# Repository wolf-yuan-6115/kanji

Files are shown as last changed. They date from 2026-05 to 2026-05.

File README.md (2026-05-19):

# Kanji

Kanji is an ESP32 based Wi-Fi smart clock. Featuring E-ink display, it can pull weather data, calendar and display realtime clock. It is designed to be a simple and elegant clock that can be placed on a desk. There's also a SHT40 temperature and humidity sensor to provide more information.

Case was not designed and it's intended to just directly use screw as stand.

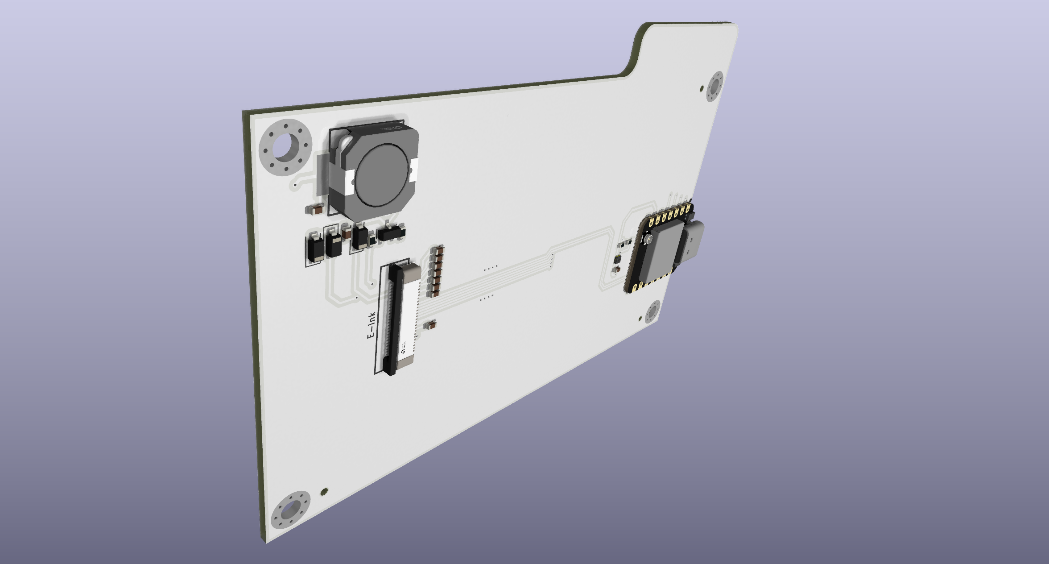
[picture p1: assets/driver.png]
Driver


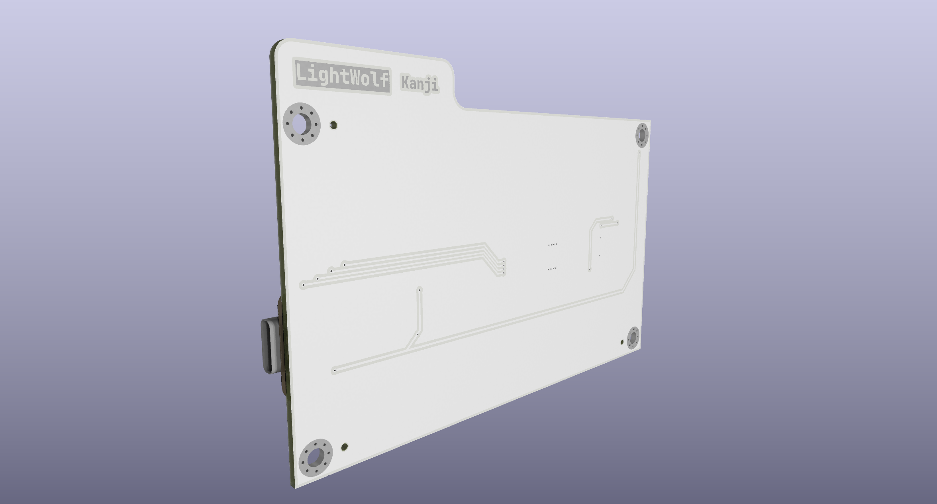
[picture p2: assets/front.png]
front


> Note that display is not here yet because it's going to order seperately.

## Schematic

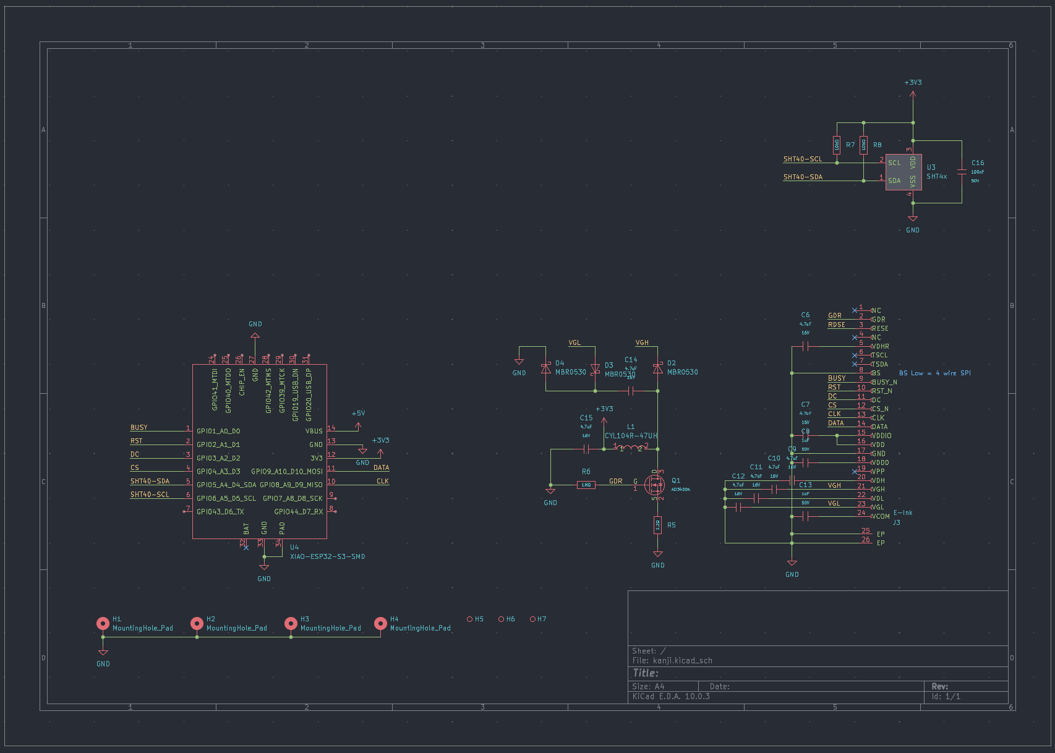
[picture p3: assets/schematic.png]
schematic


## Routing

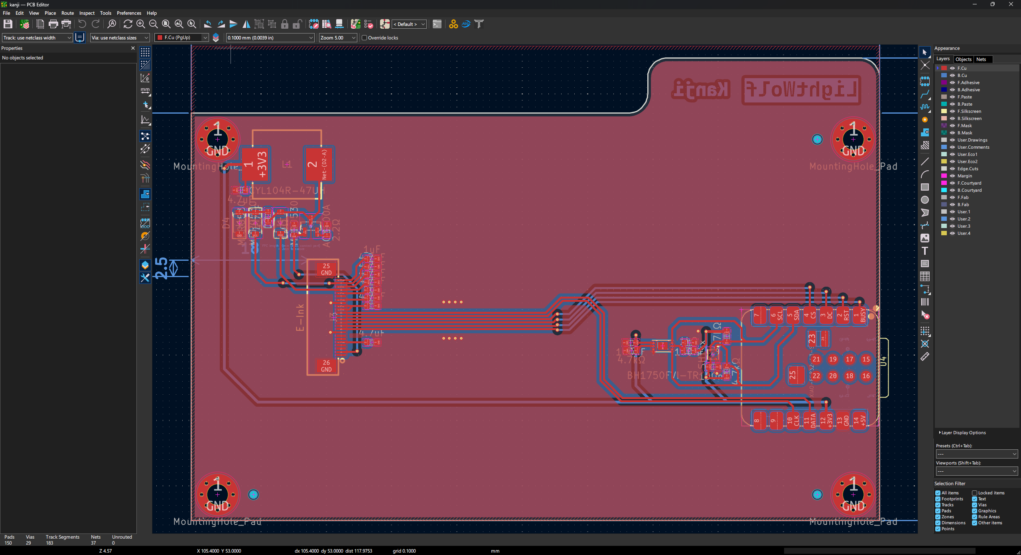
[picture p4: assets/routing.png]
routing


## BOM

| Name | Qty | Total (USD) | Distributor |
| --- | --- | --- | --- |
| WaveShare E-Ink display & Seeed Xiao ESP32-S3 | 1 | $35.00 | Taobao (Like Aliexpress but China version) |
| PCB Assambly | 1 | $44.84 | JLCPCB |
| PCB | 1 | $10.56 | JLCPCB |
| Shipping | 1 | $6.12 | JLCPCB |
| Total | 1 | $96.52 | - |

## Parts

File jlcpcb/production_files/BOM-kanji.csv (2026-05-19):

Comment | Designator | Footprint | LCSC | Quantity
100nF | C1,C16,C17 | C_0603 | C14663 | 3
1MΩ | R6 | R_0603 | C22935 | 1
1kΩ | R2 | R_0603 | C21190 | 1
1uF | C13,C8 | C_0603 | C15849 | 2
2.2Ω | R5 | R_0603 | C22939 | 1
4.7kΩ | R1,R10,R9 | R_0603 | C23162 | 3
4.7uF | C10,C11,C12,C14,C15,C6,C7,C9 | C_0603 | C19666 | 8
AO3400A | Q1 | Q_SOT-23 | C20917 | 1
BH1750FVI-TR | U1 | WSOF-6_L2.6-W1.6-P0.50-TL-EP | C78960 | 1
CYL104R-47UH | L1 | IND-SMD_L10.5-W10.5 | C7431100 | 1
E-Ink | J3 | FPC-SMD_AFC07-S24FCC-00 | C11057 | 1
MBR0530 | D2,D3,D4 | D_SOD-123 | C77336 | 3
SHT4x | U3 | Sensirion_DFN-4_1.5x1.5mm_P0.8mm_SHT4x_NoCentralPad | C2909890 | 1

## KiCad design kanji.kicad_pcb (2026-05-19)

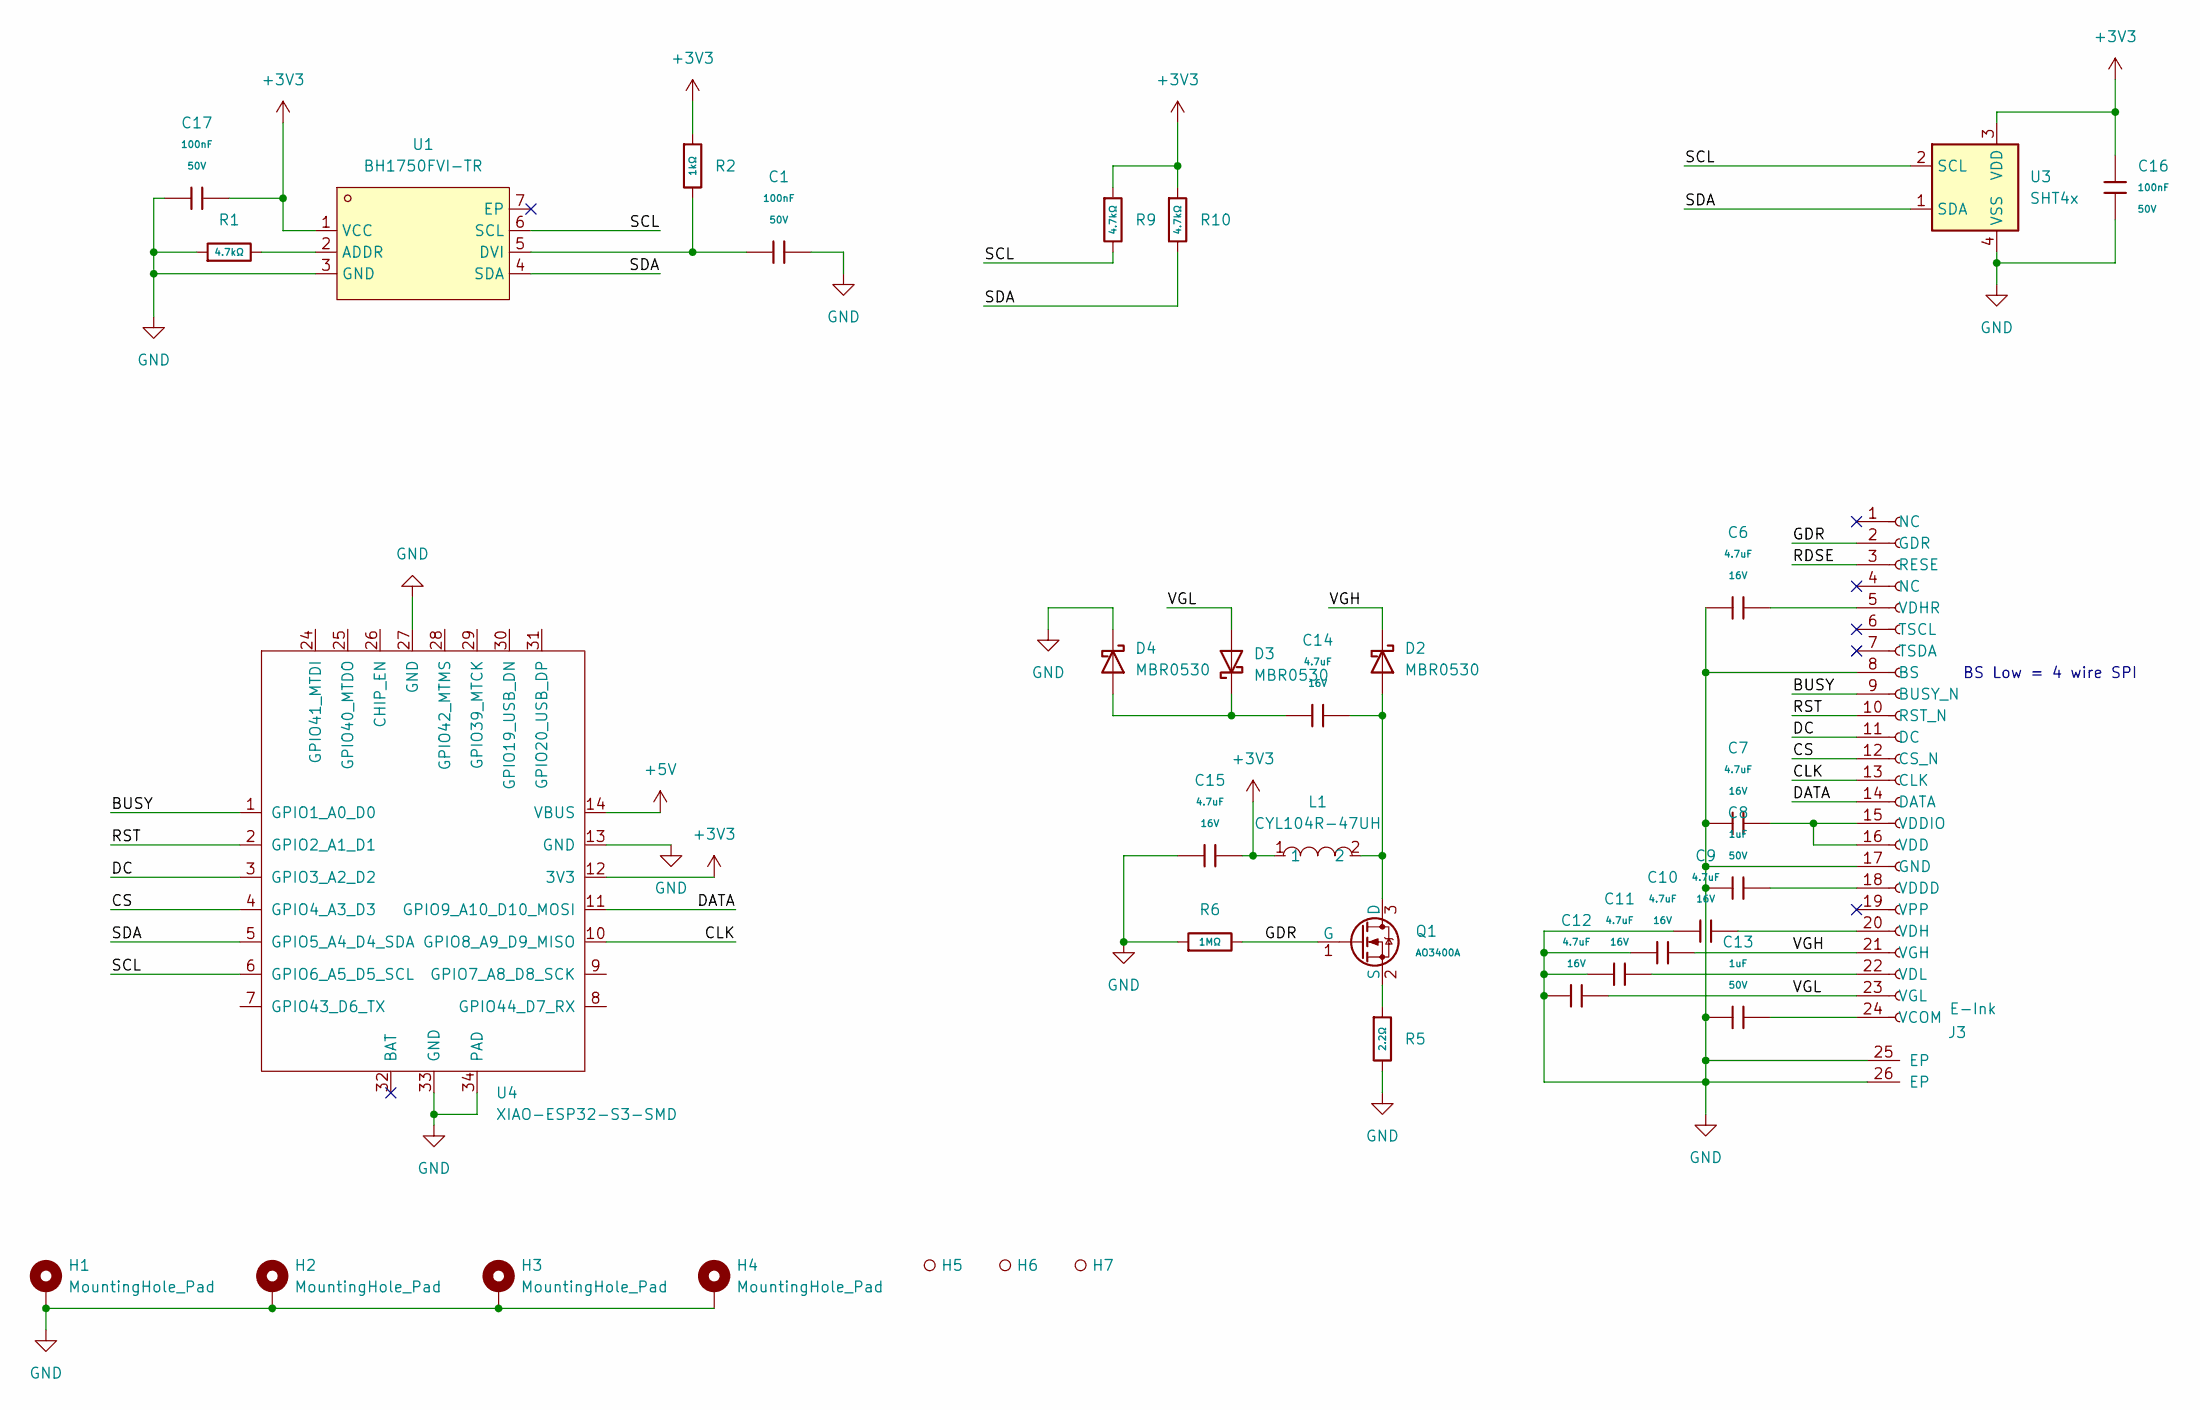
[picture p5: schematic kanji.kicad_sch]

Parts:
C1, C16, C17: 100nF; C_0603; Voltage Rated 50V; Tolerance ±10%; Part CC0603KRX7R9BB104; LCSC C14663
C6, C7, C9, C10, C11, C12, C14, C15: 4.7uF; C_0603; Voltage Rated 16V; Tolerance ±10%; Part CL10A475KO8NNNC; LCSC C19666
C8, C13: 1uF; C_0603; Voltage Rated 50V; Tolerance ±10%; Part CL10A105KB8NNNC; LCSC C15849
D2, D3, D4: MBR0530; D_SOD-123
H1, H2, H3, H4: MountingHole_Pad; MountingHole_3.2mm_M3_Pad_Via
H5, H6, H7: Hole_Tooling_JLCPCB
J3: E-Ink; FPC-SMD_AFC07-S24FCC-00
L1: CYL104R-47UH; IND-SMD_L10.5-W10.5; MPN CYL104R-47UH; LCSC Part C7431100
Q1: AO3400A; Q_SOT-23; Part AO3400A; LCSC C20917
R1, R9, R10: 4.7kΩ; R_0603; Overload Voltage (Max) 75V; Tolerance ±1%; Part 0603WAF4701T5E; LCSC C23162
R2: 1kΩ; R_0603; Overload Voltage (Max) 75V; Tolerance ±1%; Part 0603WAF1001T5E; LCSC C21190
R5: 2.2Ω; R_0603; Overload Voltage (Max) 75V; Tolerance ±1%; Part 0603WAF220KT5E; LCSC C22939
R6: 1MΩ; R_0603; Overload Voltage (Max) 75V; Tolerance ±1%; Part 0603WAF1004T5E; LCSC C22935
U1: BH1750FVI-TR; WSOF-6_L2.6-W1.6-P0.50-TL-EP; MPN BH1750FVI-TR; LCSC Part C78960
U3: SHT4x; Sensirion_DFN-4_1.5x1.5mm_P0.8mm_SHT4x_NoCentralPad; LCSC C2909890
U4: XIAO-ESP32-S3-SMD

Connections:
+3V3: C15.2, C16.1, C17.2, L1.1, R2.1, R9.1, R10.1, U1.1 (VCC), U3.3 (VDD), U4.12 (3V3)
+5V: U4.14 (VBUS)
/BUSY: J3.9 (BUSY_N), U4.1 (GPIO1_A0_D0)
/CLK: J3.13 (CLK), U4.10 (GPIO8_A9_D9_MISO)
/CS: J3.12 (CS_N), U4.4 (GPIO4_A3_D3)
/DATA: J3.14 (DATA), U4.11 (GPIO9_A10_D10_MOSI)
/DC: J3.11 (DC), U4.3 (GPIO3_A2_D2)
/GDR: J3.2 (GDR), Q1.1 (G), R6.2
/RDSE: J3.3 (RESE)
/RST: J3.10 (RST_N), U4.2 (GPIO2_A1_D1)
/SCL: R9.2, U1.6 (SCL), U3.2 (SCL), U4.6 (GPIO6_A5_D5_SCL)
/SDA: R10.2, U1.4 (SDA), U3.1 (SDA), U4.5 (GPIO5_A4_D4_SDA)
/VGH: C10.2, D2.1 (K), J3.21 (VGH)
/VGL: C12.2, D3.2 (A), J3.23 (VGL)
GND: C1.2, C6.1, C7.1, C8.1, C9.1, C10.1, C11.1, C12.1, C13.1, C15.1, C16.2, C17.1, D4.1 (K), H1.1 (1_1), H2.1 (1_1), H3.1 (1_1), H4.1 (1_1), J3.8 (BS), J3.17 (GND), J3.25 (EP), J3.26 (EP), R1.1, R5.2, R6.1, U1.3 (GND), U3.4 (VSS), U4.13 (GND), U4.27 (GND), U4.33 (GND), U4.34 (PAD)
unnamed: C14.2, D2.2 (A), L1.2, Q1.3 (D)
unnamed: C14.1, D3.1 (K), D4.2 (A)
unnamed: C13.2, J3.24 (VCOM)
unnamed: C7.2, J3.15 (VDDIO), J3.16 (VDD)
unnamed: C8.2, J3.18 (VDDD)
unnamed: C9.2, J3.20 (VDH)
unnamed: C6.2, J3.5 (VDHR)
unnamed: C11.2, J3.22 (VDL)
unnamed: Q1.2 (S), R5.1
unnamed: R1.2, U1.2 (ADDR)
unnamed: C1.1, R2.2, U1.5 (DVI)

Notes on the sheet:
BS Low = 4 wire SPI

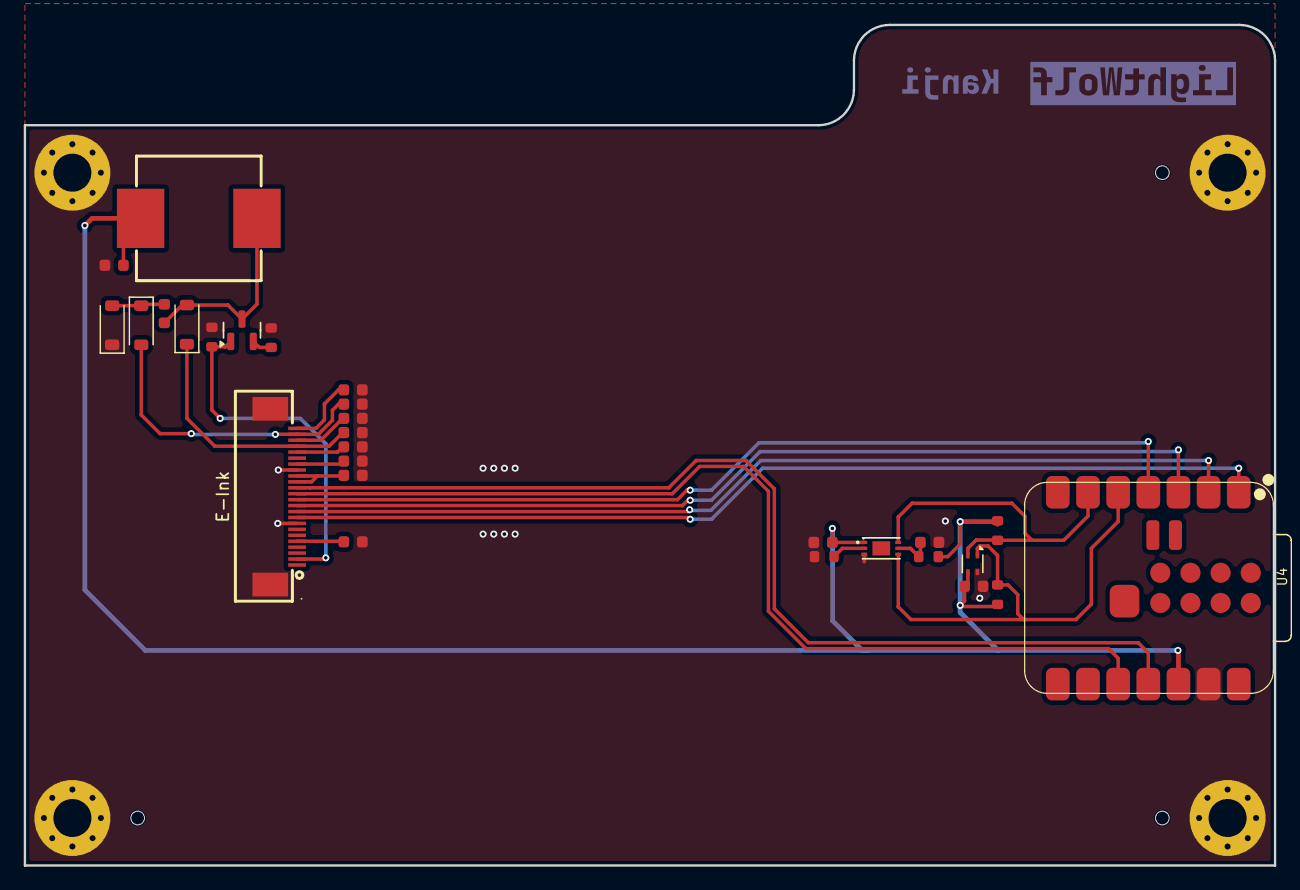
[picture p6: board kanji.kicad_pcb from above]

Board: 2 copper layers, 105.3 x 70.8 mm, 35 parts (0 on the bottom side), 24 nets.

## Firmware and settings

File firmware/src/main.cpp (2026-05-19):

#include <Arduino.h>
#include <WiFi.h>
#include <WiFiClientSecure.h>
#include <HTTPClient.h>
#include <ArduinoJson.h>
#include <time.h>
#include <Wire.h>
#include <Adafruit_SHT4x.h>
#include <esp_heap_caps.h>

#include "app_config.h"
#include "vendor/waveshare_4in26g/EPD_4in26g.h"
#include "vendor/waveshare_4in26g/GUI_Paint.h"
#include "vendor/waveshare_4in26g/fonts.h"

namespace {

constexpr int I2C_SDA_PIN = 5;
constexpr int I2C_SCL_PIN = 6;
constexpr uint32_t I2C_FREQ = 100000;
constexpr uint8_t BH1750_ADDR = 0x23;
constexpr uint32_t LIGHT_UPDATE_MS = 1000UL;
constexpr float LIGHT_PRESENT_LUX = 10.0f;
constexpr float LIGHT_ABSENT_LUX = 5.0f;
constexpr uint32_t CLOCK_REFRESH_SECONDS = 5UL * 60UL;

constexpr uint16_t DISPLAY_WIDTH = EPD_4IN26G_WIDTH;
constexpr uint16_t DISPLAY_HEIGHT = EPD_4IN26G_HEIGHT;
constexpr uint16_t LEFT_PANE_WIDTH = (DISPLAY_WIDTH * 2) / 3;
constexpr uint16_t RIGHT_PANE_X = LEFT_PANE_WIDTH;
constexpr uint16_t RIGHT_PANE_WIDTH = DISPLAY_WIDTH - LEFT_PANE_WIDTH;
constexpr uint16_t RIGHT_BOTTOM_ZONE_HEIGHT = 120;
constexpr uint16_t RIGHT_BOTTOM_Y = DISPLAY_HEIGHT - RIGHT_BOTTOM_ZONE_HEIGHT;
constexpr uint32_t SENSOR_UPDATE_MS = 5UL * 60UL * 1000UL;
constexpr uint32_t WEATHER_UPDATE_MS = 60UL * 60UL * 1000UL;
constexpr uint32_t NTP_RESYNC_MS = 24UL * 60UL * 60UL * 1000UL;

struct WeatherData {
  bool valid = false;
  int temp_c = 0;
  int humidity = 0;
  int weather_code = 0;
  int wind_kmph = 0;
  char description[40] = "--";
};

struct SensorData {
  bool valid = false;
  float temp_c = 0.0f;
  float humidity = 0.0f;
};

UBYTE* g_framebuffer = nullptr;
UDOUBLE g_framebuffer_size = 0;
bool g_using_psram = false;

Adafruit_SHT4x g_sht4;
bool g_sensor_ok = false;
WeatherData g_weather;
SensorData g_sensor;
bool g_light_sensor_ok = false;
bool g_light_present = true;
bool g_light_state_known = false;
bool g_light_present_trigger = false;
float g_light_lux = 0.0f;

uint32_t g_last_light_update = 0;
uint32_t g_last_sensor_update = 0;
uint32_t g_last_weather_update = 0;
uint32_t g_last_ntp_sync = 0;
time_t g_next_clock_refresh = 0;
bool g_pending_render = false;

tm g_timeinfo = {};
bool g_time_ok = false;

time_t nextFiveMinuteBoundary(time_t epoch) {
  return ((epoch / static_cast<time_t>(CLOCK_REFRESH_SECONDS)) + 1) * static_cast<time_t>(CLOCK_REFRESH_SECONDS);
}

void scheduleNextClockRefresh() {
  const time_t now_epoch = time(nullptr);
  if (now_epoch > 0) {
    g_next_clock_refresh = nextFiveMinuteBoundary(now_epoch);
  }
}

void advanceNextClockRefresh(time_t now_epoch) {
  if (g_next_clock_refresh == 0) {
    return;
  }

  while (g_next_clock_refresh <= now_epoch) {
    g_next_clock_refresh += static_cast<time_t>(CLOCK_REFRESH_SECONDS);
  }
}

bool bh1750WriteCommand(uint8_t command) {
  Wire.beginTransmission(BH1750_ADDR);
  Wire.write(command);
  return Wire.endTransmission() == 0;
}

bool initLightSensor() {
  g_last_light_update = millis();

  Wire.beginTransmission(BH1750_ADDR);
  if (Wire.endTransmission() != 0) {
    g_light_sensor_ok = false;
    return false;
  }

  if (!bh1750WriteCommand(0x01)) {
    g_light_sensor_ok = false;
    return false;
  }

  delay(5);

  if (!bh1750WriteCommand(0x07)) {
    g_light_sensor_ok = false;
    return false;
  }

  delay(5);

  if (!bh1750WriteCommand(0x10)) {
    g_light_sensor_ok = false;
    return false;
  }

  g_light_sensor_ok = true;
  return true;
}

bool readLightSensor(float& lux_out) {
  const uint8_t bytes_read = Wire.requestFrom(BH1750_ADDR, static_cast<uint8_t>(2));
  if (bytes_read != 2) {
    return false;
  }

  const uint16_t raw = (static_cast<uint16_t>(Wire.read()) << 8) | static_cast<uint16_t>(Wire.read());
  lux_out = static_cast<float>(raw) / 1.2f;
  return true;
}

bool pollLightSensor(uint32_t now_ms) {
  if ((now_ms - g_last_light_update) < LIGHT_UPDATE_MS) {
    return false;
  }

  g_last_light_update = now_ms;

  if (!g_light_sensor_ok && !initLightSensor()) {
    g_light_present = true;
    g_light_state_known = false;
    return false;
  }

  float lux = 0.0f;
  if (!readLightSensor(lux)) {
    g_light_sensor_ok = false;
    g_light_present = true;
    g_light_state_known = false;
    return false;
  }

  g_light_lux = lux;
  const bool was_present = g_light_present;

  if (!g_light_state_known) {
    g_light_present = lux >= LIGHT_PRESENT_LUX;
    g_light_state_known = true;
  } else if (lux >= LIGHT_PRESENT_LUX) {
    g_light_present = true;
  } else if (lux <= LIGHT_ABSENT_LUX) {
    g_light_present = false;
  }

  if (!was_present && g_light_present) {
    g_light_present_trigger = true;
    g_pending_render = true;
  }

  return true;
}

void drawWeatherIcon(uint16_t x, uint16_t y, int code) {
  if (code == 113) {
    Paint_DrawCircle(x + 20, y + 20, 12, EPD_4IN26G_YELLOW, DOT_PIXEL_1X1, DRAW_FILL_EMPTY);
    Paint_DrawLine(x + 20, y + 2, x + 20, y + 12, EPD_4IN26G_YELLOW, DOT_PIXEL_1X1, LINE_STYLE_SOLID);
    Paint_DrawLine(x + 20, y + 28, x + 20, y + 38, EPD_4IN26G_YELLOW, DOT_PIXEL_1X1, LINE_STYLE_SOLID);
    Paint_DrawLine(x + 2, y + 20, x + 12, y + 20, EPD_4IN26G_YELLOW, DOT_PIXEL_1X1, LINE_STYLE_SOLID);
    Paint_DrawLine(x + 28, y + 20, x + 38, y + 20, EPD_4IN26G_YELLOW, DOT_PIXEL_1X1, LINE_STYLE_SOLID);
    return;
  }

  if (code >= 176 && code <= 200) {
    Paint_DrawRectangle(x + 6, y + 10, x + 34, y + 26, EPD_4IN26G_BLACK, DOT_PIXEL_1X1, DRAW_FILL_EMPTY);
    Paint_DrawLine(x + 10, y + 28, x + 14, y + 36, EPD_4IN26G_RED, DOT_PIXEL_1X1, LINE_STYLE_SOLID);
    Paint_DrawLine(x + 20, y + 28, x + 24, y + 36, EPD_4IN26G_RED, DOT_PIXEL_1X1, LINE_STYLE_SOLID);
    Paint_DrawLine(x + 30, y + 28, x + 34, y + 36, EPD_4IN26G_RED, DOT_PIXEL_1X1, LINE_STYLE_SOLID);
    return;
  }

  if ((code >= 80 && code <= 99) || code == 263 || code == 266) {
    Paint_DrawRectangle(x + 6, y + 10, x + 34, y + 26, EPD_4IN26G_BLACK, DOT_PIXEL_1X1, DRAW_FILL_EMPTY);
    Paint_DrawLine(x + 10, y + 28, x + 10, y + 36, EPD_4IN26G_BLACK, DOT_PIXEL_1X1, LINE_STYLE_SOLID);
    Paint_DrawLine(x + 20, y + 28, x + 20, y + 36, EPD_4IN26G_BLACK, DOT_PIXEL_1X1, LINE_STYLE_SOLID);
    Paint_DrawLine(x + 30, y + 28, x + 30, y + 36, EPD_4IN26G_BLACK, DOT_PIXEL_1X1, LINE_STYLE_SOLID);
    return;
  }

  if (code == 116 || code == 119 || code == 122) {
    Paint_DrawRectangle(x + 6, y + 12, x + 34, y + 30, EPD_4IN26G_BLACK, DOT_PIXEL_1X1, DRAW_FILL_EMPTY);
    Paint_DrawCircle(x + 14, y + 12, 6, EPD_4IN26G_BLACK, DOT_PIXEL_1X1, DRAW_FILL_EMPTY);
    Paint_DrawCircle(x + 24, y + 10, 7, EPD_4IN26G_BLACK, DOT_PIXEL_1X1, DRAW_FILL_EMPTY);
    return;
  }

  Paint_DrawRectangle(x + 6, y + 10, x + 34, y + 28, EPD_4IN26G_BLACK, DOT_PIXEL_1X1, DRAW_FILL_EMPTY);
  Paint_DrawLine(x + 10, y + 32, x + 30, y + 32, EPD_4IN26G_YELLOW, DOT_PIXEL_1X1, LINE_STYLE_DOTTED);
}

void drawLayoutBorders() {
  Paint_DrawLine(LEFT_PANE_WIDTH, 0, LEFT_PANE_WIDTH, DISPLAY_HEIGHT - 1, EPD_4IN26G_BLACK, DOT_PIXEL_1X1, LINE_STYLE_SOLID);
  Paint_DrawLine(RIGHT_PANE_X, RIGHT_BOTTOM_Y, DISPLAY_WIDTH - 1, RIGHT_BOTTOM_Y, EPD_4IN26G_BLACK, DOT_PIXEL_1X1, LINE_STYLE_SOLID);
}

void drawClockPane() {
  char time_buf[16];
  char date_buf[24];
  if (g_time_ok) {
    strftime(time_buf, sizeof(time_buf), "%H:%M", &g_timeinfo);
    strftime(date_buf, sizeof(date_buf), "%a %Y-%m-%d", &g_timeinfo);
  } else {
    snprintf(time_buf, sizeof(time_buf), "--:--");
    snprintf(date_buf, sizeof(date_buf), "No time sync");
  }

  Paint_DrawString_EN(24, 36, "Clock", &Font20, EPD_4IN26G_BLACK, EPD_4IN26G_WHITE);
  Paint_DrawString_EN(24, 140, time_buf, &Font24, EPD_4IN26G_RED, EPD_4IN26G_WHITE);
  Paint_DrawString_EN(24, 190, date_buf, &Font16, EPD_4IN26G_BLACK, EPD_4IN26G_WHITE);

  if (g_time_ok) {
    char tz_buf[24];
    strftime(tz_buf, sizeof(tz_buf), "%Z", &g_timeinfo);
    Paint_DrawString_EN(24, 222, tz_buf, &Font12, EPD_4IN26G_YELLOW, EPD_4IN26G_WHITE);
  }
}

void drawWeatherPane() {
  Paint_DrawString_EN(RIGHT_PANE_X + 14, 20, "Weather", &Font16, EPD_4IN26G_BLACK, EPD_4IN26G_WHITE);
  drawWeatherIcon(RIGHT_PANE_X + 18, 48, g_weather.weather_code);

  char buf[48];
  if (g_weather.valid) {
    snprintf(buf, sizeof(buf), "%d C", g_weather.temp_c);
    Paint_DrawString_EN(RIGHT_PANE_X + 70, 66, buf, &Font20, EPD_4IN26G_RED, EPD_4IN26G_WHITE);

    snprintf(buf, sizeof(buf), "RH %d%%", g_weather.humidity);
    Paint_DrawString_EN(RIGHT_PANE_X + 14, 110, buf, &Font16, EPD_4IN26G_BLACK, EPD_4IN26G_WHITE);

    snprintf(buf, sizeof(buf), "Wind %dkm", g_weather.wind_kmph);
    Paint_DrawString_EN(RIGHT_PANE_X + 14, 138, buf, &Font12, EPD_4IN26G_YELLOW, EPD_4IN26G_WHITE);

    Paint_DrawString_EN(RIGHT_PANE_X + 14, 162, g_weather.description, &Font12, EPD_4IN26G_BLACK, EPD_4IN26G_WHITE);
  } else {
    Paint_DrawString_EN(RIGHT_PANE_X + 14, 100, "No weather", &Font16, EPD_4IN26G_BLACK, EPD_4IN26G_WHITE);
  }
}

void drawSensorZone() {
  Paint_DrawString_EN(RIGHT_PANE_X + 14, RIGHT_BOTTOM_Y + 12, "Room", &Font16, EPD_4IN26G_BLACK, EPD_4IN26G_WHITE);

  char buf[48];
  if (g_sensor.valid) {
    snprintf(buf, sizeof(buf), "T %.1f C", g_sensor.temp_c);
    Paint_DrawString_EN(RIGHT_PANE_X + 14, RIGHT_BOTTOM_Y + 44, buf, &Font16, EPD_4IN26G_RED, EPD_4IN26G_WHITE);

    snprintf(buf, sizeof(buf), "RH %.1f%%", g_sensor.humidity);
    Paint_DrawString_EN(RIGHT_PANE_X + 14, RIGHT_BOTTOM_Y + 72, buf, &Font16, EPD_4IN26G_BLACK, EPD_4IN26G_WHITE);
  } else {
    Paint_DrawString_EN(RIGHT_PANE_X + 14, RIGHT_BOTTOM_Y + 50, "SHT40 offline", &Font16, EPD_4IN26G_BLACK, EPD_4IN26G_WHITE);
  }
}

void renderAndFlush() {
  Paint_NewImage(g_framebuffer, DISPLAY_WIDTH, DISPLAY_HEIGHT, 0, EPD_4IN26G_WHITE);
  Paint_SetScale(4);
  Paint_SelectImage(g_framebuffer);
  Paint_Clear(EPD_4IN26G_WHITE);

  drawLayoutBorders();
  drawClockPane();
  drawWeatherPane();
  drawSensorZone();

  EPD_4IN26G_Display(g_framebuffer);
}

bool connectWiFi(uint32_t timeout_ms) {
  if (WiFi.status() == WL_CONNECTED) {
    return true;
  }

  WiFi.mode(WIFI_STA);
  WiFi.begin(WIFI_SSID, WIFI_PASSWORD);
  const uint32_t start_ms = millis();
  while (WiFi.status() != WL_CONNECTED && (millis() - start_ms) < timeout_ms) {
    delay(250);
  }
  return WiFi.status() == WL_CONNECTED;
}

bool syncTime() {
  configTzTime(TIMEZONE_TZ, NTP_SERVER_PRIMARY, NTP_SERVER_SECONDARY);
  for (int i = 0; i < 20; ++i) {
    if (getLocalTime(&g_timeinfo, 500)) {
      g_time_ok = true;
      g_last_ntp_sync = millis();
      scheduleNextClockRefresh();
      return true;
    }
    delay(200);
  }
  g_time_ok = false;
  return false;
}

bool refreshLocalTime() {
  g_time_ok = getLocalTime(&g_timeinfo, 100);
  return g_time_ok;
}

bool fetchWeather() {
  if (WiFi.status() != WL_CONNECTED) {
    return false;
  }

  WiFiClientSecure client;
  client.setInsecure();

  HTTPClient http;
  if (!http.begin(client, WEATHER_URL)) {
    return false;
  }

  http.setTimeout(7000);
  const int code = http.GET();
  if (code != HTTP_CODE_OK) {
    http.end();
    return false;
  }

  JsonDocument doc;
  DeserializationError err = deserializeJson(doc, http.getStream());
  http.end();
  if (err) {
    return false;
  }

  JsonVariant current = doc["current_condition"][0];
  if (current.isNull()) {
    return false;
  }

  g_weather.temp_c = atoi(current["temp_C"] | "0");
  g_weather.humidity = atoi(current["humidity"] | "0");
  g_weather.weather_code = atoi(current["weatherCode"] | "0");
  g_weather.wind_kmph = atoi(current["windspeedKmph"] | "0");

  const char* desc = current["weatherDesc"][0]["value"] | "--";
  strncpy(g_weather.description, desc, sizeof(g_weather.description) - 1);
  g_weather.description[sizeof(g_weather.description) - 1] = '\0';

  g_weather.valid = true;
  g_last_weather_update = millis();
  return true;
}

bool readSensor() {
  if (!g_sensor_ok) {
    g_sensor.valid = false;
    return false;
  }

  sensors_event_t humidity_event;
  sensors_event_t temp_event;
  if (!g_sht4.getEvent(&humidity_event, &temp_event)) {
    g_sensor.valid = false;
    return false;
  }

  g_sensor.temp_c = temp_event.temperature;
  g_sensor.humidity = humidity_event.relative_humidity;
  g_sensor.valid = true;
  g_last_sensor_update = millis();
  g_pending_render = true;
  return true;
}

bool allocateFramebuffer() {
  g_framebuffer_size = ((DISPLAY_WIDTH % 4 == 0) ? (DISPLAY_WIDTH / 4) : (DISPLAY_WIDTH / 4 + 1)) * DISPLAY_HEIGHT;

  if (psramFound()) {
    g_framebuffer = static_cast<UBYTE*>(heap_caps_malloc(g_framebuffer_size, MALLOC_CAP_SPIRAM | MALLOC_CAP_8BIT));
    if (g_framebuffer != nullptr) {
      g_using_psram = true;
      return true;
    }
  }

  g_framebuffer = static_cast<UBYTE*>(malloc(g_framebuffer_size));
  g_using_psram = false;
  return g_framebuffer != nullptr;
}

void printStartupStatus() {
  Serial.printf("Framebuffer bytes: %lu\n", static_cast<unsigned long>(g_framebuffer_size));
  Serial.printf("Framebuffer memory: %s\n", g_using_psram ? "PSRAM" : "INTERNAL");
  Serial.printf("WiFi connected: %s\n", WiFi.status() == WL_CONNECTED ? "yes" : "no");
  Serial.printf("SHT40 online: %s\n", g_sensor_ok ? "yes" : "no");
  Serial.printf("BH1750 online: %s\n", g_light_sensor_ok ? "yes" : "no");
  if (g_light_sensor_ok) {
    Serial.printf("Light present: %s (%.1f lux)\n", g_light_present ? "yes" : "no", g_light_lux);
  }
  Serial.printf("Time synced: %s\n", g_time_ok ? "yes" : "no");
  if (g_next_clock_refresh != 0) {
    Serial.printf("Next clock refresh: %lu\n", static_cast<unsigned long>(g_next_clock_refresh));
  }
}

}  // namespace

void setup() {
  Serial.begin(115200);
  delay(500);

  DEV_Module_Init();
  EPD_4IN26G_Init();
  EPD_4IN26G_Clear(EPD_4IN26G_WHITE);

  if (!allocateFramebuffer()) {
    Serial.println("Framebuffer allocation failed");
    while (true) {
      delay(1000);
    }
  }

  Wire.begin(I2C_SDA_PIN, I2C_SCL_PIN, I2C_FREQ);
  initLightSensor();
  g_sensor_ok = g_sht4.begin(&Wire);
  if (g_sensor_ok) {
    g_sht4.setPrecision(SHT4X_HIGH_PRECISION);
    g_sht4.setHeater(SHT4X_NO_HEATER);
    readSensor();
  }

  connectWiFi(15000);
  syncTime();
  fetchWeather();
  refreshLocalTime();
  if (g_time_ok) {
    scheduleNextClockRefresh();
  }

  printStartupStatus();
  renderAndFlush();

  const uint32_t now = millis();
  g_last_light_update = now;
  if (g_last_sensor_update == 0) {
    g_last_sensor_update = now;
  }
  if (g_last_weather_update == 0) {
    g_last_weather_update = now;
  }
}

void loop() {
  const uint32_t now = millis();

  if (WiFi.status() != WL_CONNECTED) {
    connectWiFi(10000);
  }

  if ((now - g_last_ntp_sync) >= NTP_RESYNC_MS) {
    syncTime();
  } else {
    refreshLocalTime();
  }

  if ((now - g_last_light_update) >= LIGHT_UPDATE_MS) {
    pollLightSensor(now);
  }

  if ((now - g_last_sensor_update) >= SENSOR_UPDATE_MS) {
    readSensor();
  }

  if ((now - g_last_weather_update) >= WEATHER_UPDATE_MS) {
    if (fetchWeather()) {
      g_pending_render = true;
    }
  }

  if (g_time_ok && g_next_clock_refresh != 0) {
    const time_t current_epoch = time(nullptr);
    if (current_epoch >= g_next_clock_refresh) {
      advanceNextClockRefresh(current_epoch);
      g_pending_render = true;
    }
  }

  const bool light_gate_open = !g_light_sensor_ok || g_light_present;
  if (g_light_present_trigger || (light_gate_open && g_pending_render)) {
    renderAndFlush();
    g_pending_render = false;
    g_light_present_trigger = false;
  }

  delay(500);
}

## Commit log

2026-05-18 feat: init design
    [BOM-kanji.csv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]
2026-05-19 feat: add light sensor logic
2026-05-19 feat: add light sensor
    [BOM-kanji.csv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]
2026-05-19 feat: update bom due to new als
